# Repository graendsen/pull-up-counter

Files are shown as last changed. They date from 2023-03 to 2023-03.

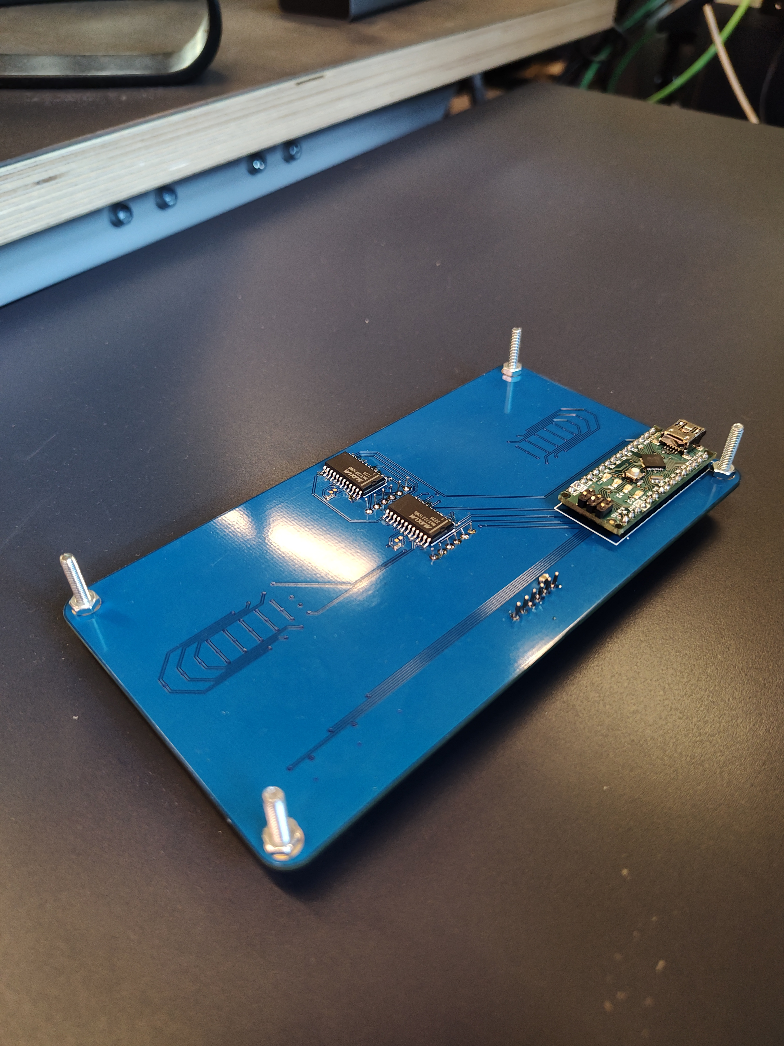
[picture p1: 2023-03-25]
Pictures/Bottom.jpg

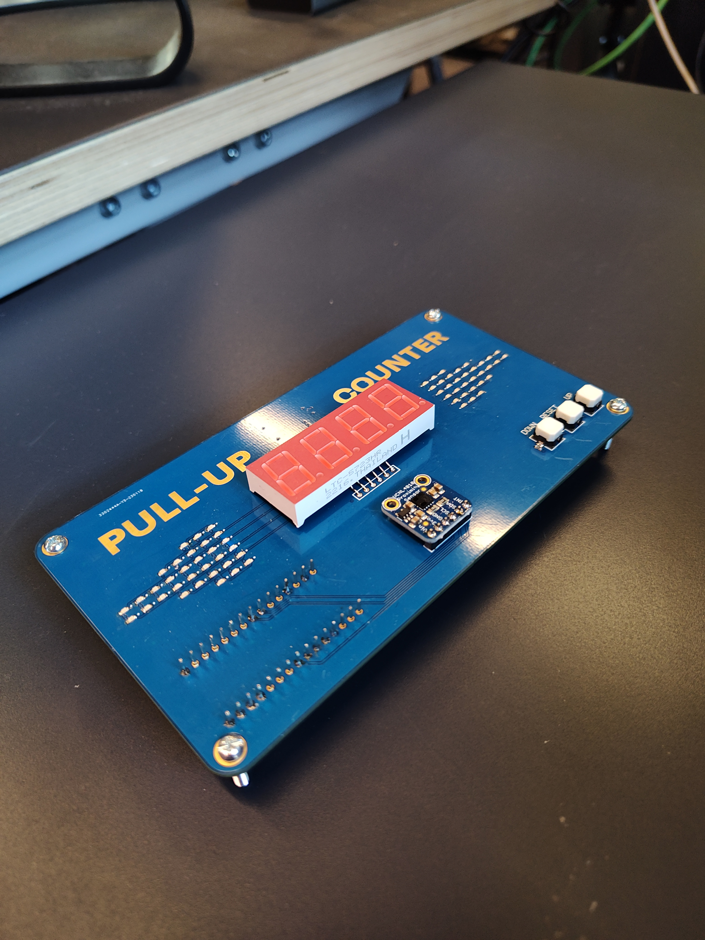
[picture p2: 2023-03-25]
Pictures/Top.jpg

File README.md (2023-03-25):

# pull-up-counter
A simple pull-up counter that can hang above a pull-up bar or fingerboard. The counter simply accumulates all registered pull-ups, and stores the number in case of shutdown. 

The number can be manually adjusted with the tactile switches. In order to reset the counter to 0, the RESET button must be held in for 2 seconds.

Placement
## Folders
[Hardware](Hardware) - Schematics and Altium designer files

[Mechanics](Mechanics) - Stl files for optional fixtures/enclosures

[Pictures](Pictures) - Photographs of the system

[Production](Production) - BoM, gerbers, placement information

[Software](Software) - Arduino files

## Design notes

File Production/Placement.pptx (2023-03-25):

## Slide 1

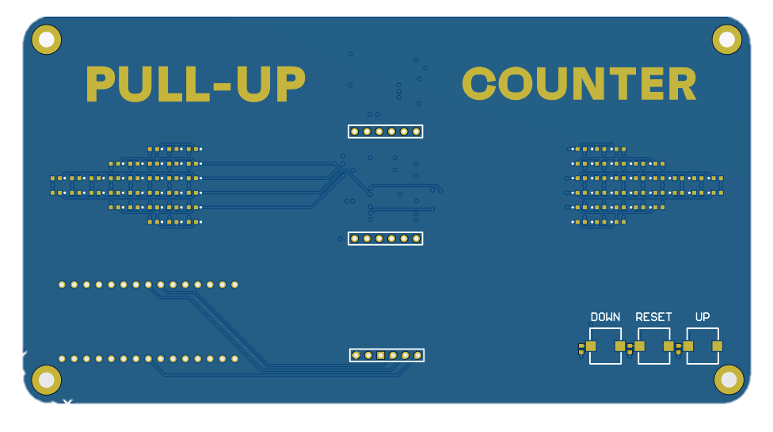
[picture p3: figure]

MD3
7-segment display

D1-D32
Success LEDs

D33-D64
Success LEDs

SW1-SW3
Tactile switches
R2-R4
Resistors

MD2
Proximity sensor

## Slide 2

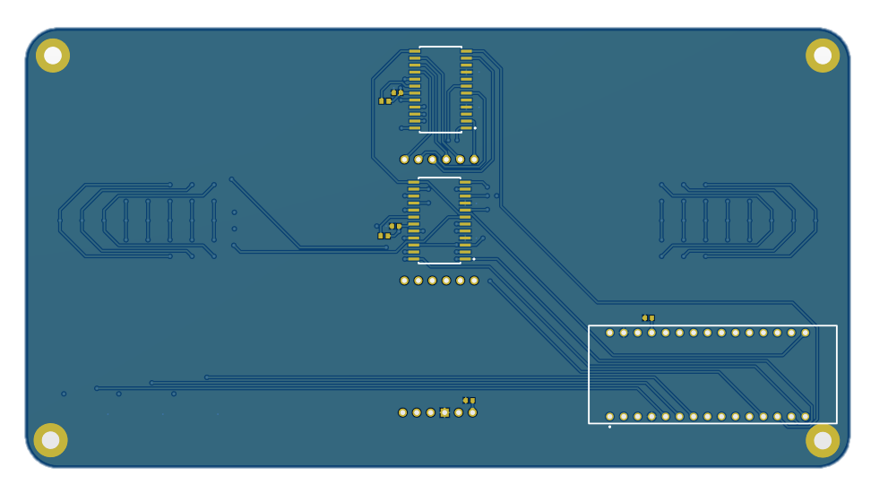
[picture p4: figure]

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
Arduino Nano

C3

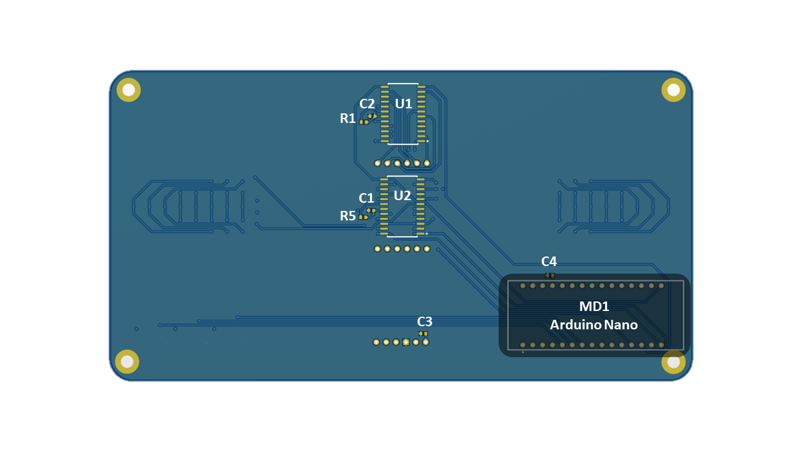
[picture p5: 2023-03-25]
Production/Placement_bot.png

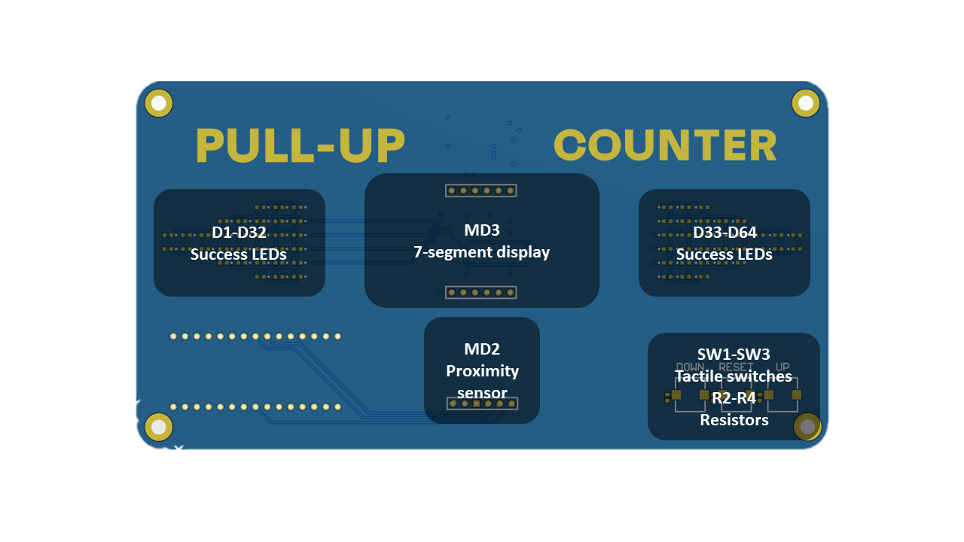
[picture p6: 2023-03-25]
Production/Placement_top.png

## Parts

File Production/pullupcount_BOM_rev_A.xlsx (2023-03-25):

Circuit board | Pull-up counter v1.0
BOM date | March 22, 2023
BOM revision | A
Designator | Quantity | Description | Value | Manufacturer | Manufacturer part number | Footprint | Comment
C1, C2, C3 | 3 | Ceramic capacitor 6V | 1 uF | N/A | N/A | SMD 0603
C4 | 1 | Ceramic capacitor 6V | 10 uF | N/A | N/A | SMD 0603
D1, D2, D3, D4, D5, D6, D7, D8, D9, D10, D11, D12, D13, D14, D15, D16, D17, D18, D19, D20, D21, D22, D23, D24, D25, D26, D27, D28, D29, D30, D31, D32, D33, D34, D35, D36, D37, D38, D39, D40, D41, D42, D43, D44, D45, D46, D47, D48, D49, D50, D51, D52, D53, D54, D55, D56, D57, D58, D59, D60, D61, D62, D63, D64 | 64 | Blue LED 20mA |  | Wurth Elektronik | 150060BS55040 | SMD 0603
MD1 | 1 | Arduino Nano |  | Arduino | A000005 | T/H 2x15 2.54mm
MD2 | 1 | Adafruit VCNL4010 proximity sensor module |  | Adafruit | 466 | T/H 1x6 2.54mm
MD3 | 1 | LED display 4 digit 7 segment common cathode |  | Lite-On | LTC-5723HR | T/H 2x6 2.54mm | A display with 22mm separation between pin rows is preferred (like sparkfun displays with 20mm character height), but can be hard to find in stock.
R1, R2, R3, R4, R5 | 5 | SMD resistor 10 mW | 10 kOhm | N/A | N/A | SMD 0603
SW1, SW2, SW3 | 3 | Tactile switch |  | Omron Electronics | B3AL-1003P | SMD
U1, U2 | 2 | MAX7221 LED display driver |  | Maxim Integrated | MAX7221CWG+ | SOIC-24

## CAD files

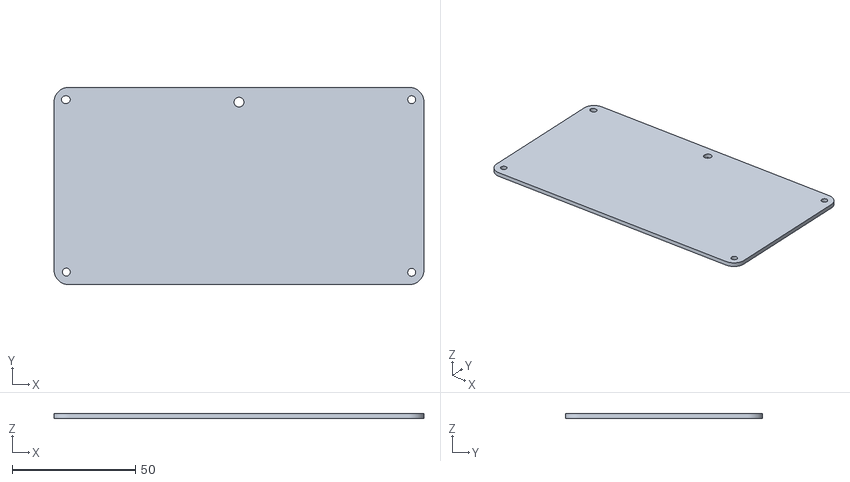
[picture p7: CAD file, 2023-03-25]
Mechanics/Pull-up counter backplate.stl
150.0 x 80.0 x 2.00

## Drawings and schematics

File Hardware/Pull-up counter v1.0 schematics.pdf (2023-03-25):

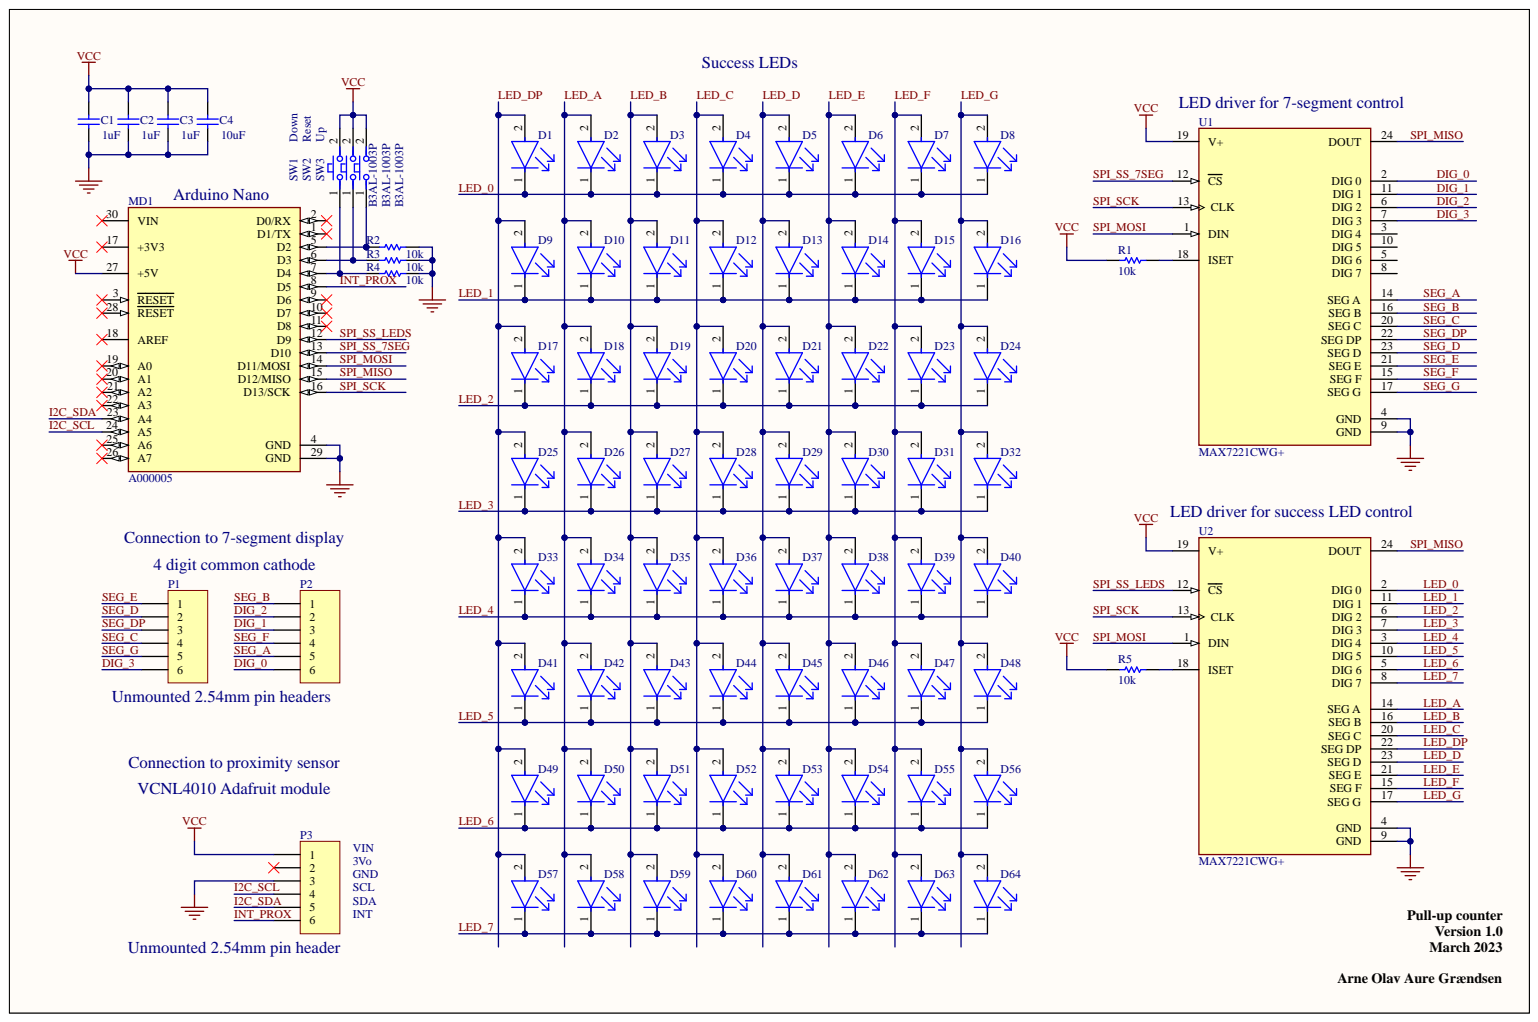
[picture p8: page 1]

LED driver for 7-segment control

LED driver for success LED control

Connection to 7-segment display
4 digit common cathode

Connection to proximity sensor
VCNL4010 Adafruit module

Pull-up counter Version 1.0

Arne Olav Aure Gr

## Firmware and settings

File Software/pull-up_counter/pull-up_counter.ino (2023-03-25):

#include <Wire.h>
#include <SPI.h>
#include <EEPROM.h>

#include "LedMatrix.h"
#include "Adafruit_VCNL4010.h"
#include "LedControl.h"

#define DOWN_BUTTON 4
#define RESET_BUTTON 3
#define UP_BUTTON 2
#define LM_CS_PIN 9
#define SEG_CS_PIN 10

LedMatrix leds(LM_CS_PIN, false);                   // Success LEDs
LedControl segment=LedControl(11,13,SEG_CS_PIN,1);  // 7-segment display
Adafruit_VCNL4010 vcnl;                             // Proximity sensor

int delayLeftRight = 60;        // Delay between lighting up each column of success LEDs
int detectedDistance = 2350;    // Raw distance number from proximity sensor. Numbers lower than this will result in detection.
int delayAfterPullup = 500;     // Delay (in milliseconds) after pullup

int detectedState = 0;
int lastDetectedState = 0;

uint16_t pullupCount = (uint16_t)EEPROM.read(0) |
                       ((uint16_t)EEPROM.read(1) << 8);


void setup() {

    Serial.begin(9600);
    Serial.println("Pull-up counter start.");
    
    pinMode(DOWN_BUTTON,INPUT);
    pinMode(RESET_BUTTON,INPUT);
    pinMode(UP_BUTTON,INPUT);
    
    segInit();
    segNum(pullupCount);

    if (! vcnl.begin()){
        Serial.println("Proximity sensor not found :(");
        while (1);
    }

    Serial.println("Found proximity sensor.");
}

void loop() {

    buttonCheck();

    if (vcnl.readProximity() < detectedDistance){
        detectedState = false;
    }else{
        detectedState = true;
    }

    if (detectedState != lastDetectedState){
        if (detectedState == true) {
            pullupCount++;
  
            segInit();
            segNum(pullupCount);
            segClose();
        
            ledsInit();
            ledsLeftRight(30);
            ledsClose();
            
            EEPROM.put(0,pullupCount);
            
        }
    delay(delayAfterPullup);
    
    }

    lastDetectedState = detectedState;
  
}

void buttonCheck(){
    int downState = digitalRead(DOWN_BUTTON);
    int upState = digitalRead(UP_BUTTON);
    int resetState = digitalRead(RESET_BUTTON);
    
    if (downState == HIGH){
        pullupCount--;
        segInit();
        segNum(pullupCount);
        segClose();
        delay(150);
    }
    if (upState == HIGH){
        pullupCount++;
        segInit();
        segNum(pullupCount);
        segClose();
        delay(150);
    }
    if (resetState == HIGH){
        delay(2000);
        if (resetState == HIGH){
            pullupCount = 0;
            segInit();
            segNum(pullupCount);
            segClose();
            delay(150);
        }
    }
}

void segNum(int number){
    segment.shutdown(0,false);   // MAX7221 is in power saving mode, so we have to wake it up
    segment.setIntensity(0,15);  // Setting brightness, max 15
    segment.clearDisplay(0);     // clearing display

    segment.setDigit(0,3,number % 10, false);
    number /=10;
    segment.setDigit(0,2,number % 10, false);
    number /=10;
    segment.setDigit(0,1,number % 10, false);
    number /=10;
    segment.setDigit(0,0,number % 10, false);
    number /=10;
    return 0;
}

void segInit(){
    segment.shutdown(0,false);   // MAX7221 is in power saving mode, so we have to wake it up
    segment.setIntensity(0,15);  // Setting brightness, max 15
    segment.clearDisplay(0);     // clearing display
}

void segClose(){
    SPI.end();
}

void ledsInit(){
    leds.begin();
    leds.setIntensity(3);
}

void ledsClose(){
    for (int i = 0; i < 8; i++){
        for (int j = 0; j < 8; j++){    
            leds.clearBufferPixel(i, j);
        }
    }
    leds.sendBuffer();  
    SPI.end();
}

void ledsLeftRight(int dly){
    leds.setBufferPixel(2, 0);
    leds.setBufferPixel(7, 0);
    leds.setBufferPixel(7, 1);     
    leds.setBufferPixel(7, 2);
    leds.setBufferPixel(7, 3);
    leds.setBufferPixel(2, 3);   
    leds.setBufferPixel(2, 4);
    leds.setBufferPixel(7, 4);
    leds.setBufferPixel(7, 5);   
    leds.setBufferPixel(7, 6);
    leds.setBufferPixel(7, 7);
    leds.setBufferPixel(2, 7);
    leds.sendBuffer();    
    delay(dly);
    leds.setBufferPixel(1, 0);
    leds.setBufferPixel(6, 0);
    leds.setBufferPixel(6, 1);
    leds.setBufferPixel(6, 2);
    leds.setBufferPixel(6, 3);
    leds.setBufferPixel(1, 3);
    leds.setBufferPixel(1, 4);
    leds.setBufferPixel(6, 4);
    leds.setBufferPixel(6, 5); 
    leds.setBufferPixel(6, 6); 
    leds.setBufferPixel(1, 7);
    leds.setBufferPixel(6, 7);
    leds.sendBuffer();  
    delay(dly);
    leds.setBufferPixel(0, 0);
    leds.setBufferPixel(5, 0); 
    leds.setBufferPixel(5, 1);
    leds.setBufferPixel(5, 2);
    leds.setBufferPixel(5, 3);
    leds.setBufferPixel(0, 3);
    leds.setBufferPixel(0, 4); 
    leds.setBufferPixel(5, 4);
    leds.setBufferPixel(5, 5);
    leds.setBufferPixel(5, 6);
    leds.setBufferPixel(5, 7);
    leds.setBufferPixel(0, 7);
    leds.sendBuffer();  
    delay(dly);
    leds.setBufferPixel(4, 0);
    leds.setBufferPixel(4, 1);
    leds.setBufferPixel(4, 2);
    leds.setBufferPixel(4, 3);
    leds.setBufferPixel(4, 4);
    leds.setBufferPixel(4, 5);
    leds.setBufferPixel(4, 6);
    leds.setBufferPixel(4, 7);
    leds.sendBuffer();  
    delay(dly);
    leds.setBufferPixel(3, 0);
    leds.setBufferPixel(3, 1);
    leds.setBufferPixel(3, 2);
    leds.setBufferPixel(3, 3);
    leds.setBufferPixel(3, 4);
    leds.setBufferPixel(3, 5);  
    leds.setBufferPixel(3, 6);
    leds.setBufferPixel(3, 7);
    leds.sendBuffer();  
    delay(dly);
    leds.setBufferPixel(2, 1);
    leds.setBufferPixel(2, 2);
    leds.setBufferPixel(2, 5);
    leds.setBufferPixel(2, 6);
    leds.sendBuffer();  
    delay(dly);
    leds.setBufferPixel(1, 1);
    leds.setBufferPixel(1, 2);
    leds.setBufferPixel(1, 5);
    leds.setBufferPixel(1, 6);
    leds.sendBuffer();  
    delay(dly);
    leds.setBufferPixel(0, 1);
    leds.setBufferPixel(0, 2);
    leds.setBufferPixel(0, 5);
    leds.setBufferPixel(0, 6);
    leds.sendBuffer();  
    dly = dly/2;
    delay(dly);
    leds.clearBufferPixel(2, 0);
    leds.clearBufferPixel(7, 0);
    leds.clearBufferPixel(7, 1);     
    leds.clearBufferPixel(7, 2);
    leds.clearBufferPixel(7, 3);
    leds.clearBufferPixel(2, 3);   
    leds.clearBufferPixel(2, 4);
    leds.clearBufferPixel(7, 4);
    leds.clearBufferPixel(7, 5);   
    leds.clearBufferPixel(7, 6);
    leds.clearBufferPixel(7, 7);
    leds.clearBufferPixel(2, 7);
    leds.sendBuffer();    
    delay(dly);
    leds.clearBufferPixel(1, 0);
    leds.clearBufferPixel(6, 0);
    leds.clearBufferPixel(6, 1);
    leds.clearBufferPixel(6, 2);
    leds.clearBufferPixel(6, 3);
    leds.clearBufferPixel(1, 3);
    leds.clearBufferPixel(1, 4);
    leds.clearBufferPixel(6, 4);
    leds.clearBufferPixel(6, 5); 
    leds.clearBufferPixel(6, 6); 
    leds.clearBufferPixel(1, 7);
    leds.clearBufferPixel(6, 7);
    leds.sendBuffer();  
    delay(dly);
    leds.clearBufferPixel(0, 0);
    leds.clearBufferPixel(5, 0); 
    leds.clearBufferPixel(5, 1);
    leds.clearBufferPixel(5, 2);
    leds.clearBufferPixel(5, 3);
    leds.clearBufferPixel(0, 3);
    leds.clearBufferPixel(0, 4); 
    leds.clearBufferPixel(5, 4);
    leds.clearBufferPixel(5, 5);
    leds.clearBufferPixel(5, 6);
    leds.clearBufferPixel(5, 7);
    leds.clearBufferPixel(0, 7);
    leds.sendBuffer();  
    delay(dly);
    leds.clearBufferPixel(4, 0);
    leds.clearBufferPixel(4, 1);
    leds.clearBufferPixel(4, 2);
    leds.clearBufferPixel(4, 3);
    leds.clearBufferPixel(4, 4);
    leds.clearBufferPixel(4, 5);
    leds.clearBufferPixel(4, 6);
    leds.clearBufferPixel(4, 7);
    leds.sendBuffer();  
    delay(dly);
    leds.clearBufferPixel(3, 0);
    leds.clearBufferPixel(3, 1);
    leds.clearBufferPixel(3, 2);
    leds.clearBufferPixel(3, 3);
    leds.clearBufferPixel(3, 4);
    leds.clearBufferPixel(3, 5);  
    leds.clearBufferPixel(3, 6);
    leds.clearBufferPixel(3, 7);
    leds.sendBuffer();  
    delay(dly);
    leds.clearBufferPixel(2, 1);
    leds.clearBufferPixel(2, 2);
    leds.clearBufferPixel(2, 5);
    leds.clearBufferPixel(2, 6);
    leds.sendBuffer();  
    delay(dly);
    leds.clearBufferPixel(1, 1);
    leds.clearBufferPixel(1, 2);
    leds.clearBufferPixel(1, 5);
    leds.clearBufferPixel(1, 6);
    leds.sendBuffer();  
    delay(dly);
    leds.clearBufferPixel(0, 1);
    leds.clearBufferPixel(0, 2);
    leds.clearBufferPixel(0, 5);
    leds.clearBufferPixel(0, 6);
    leds.sendBuffer();  
}
